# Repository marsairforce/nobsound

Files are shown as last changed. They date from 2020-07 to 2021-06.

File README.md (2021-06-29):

# Nobsound Tube Audio Amplifier Upgrade

I have [This](https://www.amazon.ca/Nobsound-Amplifier-Single-Ended-Handcrafted-Headphone/dp/B073ZXZ3Z5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) audio amplifier.

Specifications:

* Output power: 6.8W * 2
* Frequency response: 20Hz-20KHz
* Input impedance: 100K ohms
* Output impedance: 4/8Ω
* SNR: 90db
* Input Sensitivity: 500mv-2000mv
* Harmonic distortion: 1% (1KHz)
* Tubes
  * 1x 5Z4P
  * 2x 6H8C
  * 4x 6P1
* Operating voltage: 110V
* Weight: about 7 kg
* Size: 260mm x 215mm(including terminals and knobs 260mm) x 150mm (W*D*H)

Chassis is close to the Hammond [1441-22BK3](https://www.hammfg.com/files/parts/pdf/1441-22BK3.pdf)

It worked well for about a year.  But now there are some issues.

## Issues

* The rectifier tube is very noisy with 120Hz. Dynamic microphones anywhere within 1M of this amp pick up the hum when the amp is on. I did not notice or care about the EM radiation before I started using microphones on my desk. For a long time I had terrible hum coming through all my recorded audio. I just thought it was the shitty microphone, or the Art Tube MPC was not very good. But all along, it was the rectifier on my power amp.

* The amplifier gets quite hot. Even the audio transformers are almost too hot to the touch. I expect the tubes to be hot and the power transformer. But there is enough heat that it conducts onto the audio output transformer case. This is too hot I feel to put the amplifier in the shelf on my desk. I currently have it on top of the shelf. That allows heat to rise away from it better. But I would prefer to have it in my shelf and not worry about it lighting up my room. I think the heat is due to the five tubes here. If we had less tubes, there would be less heat. Particularly that rectifier tube.

* Why does a hi-fi audio amplifer even use a rectifier tube. Rectifiers have a lot of internal resistance. This creates a "spongy" effect when there is more demand for power, the output voltage is reduced. This cause compression or or reduced headroom on the output sound. Which is completely not what we want here. This is something perhaps useful in a guitar amplifier right. I think the only reason they used a rectifier tube instead of diodes here is because it looks cool. Or perhaps so they could say "all tube" (so a marketing reason).

* The preamp tube is recently gone bad. I hear terrible crackling on the left speaker. I tested this by swapping the preamp tubes and then had crackling on the right side.

* The balance of the audio is not equal on both sides. I hear a very noticable reduced volume from the left speaker. At first I thought it was the position of the speakers in the room or how I sit relative to the speakers. But I was able to swap the 6P1 tubes and then have a reduced volume output on the right side.

* Retubing this amp is about $200. And that is even when I can find these tubes. The 6H8C preamp tube is about $30 USD. But I can't even find the 6P21 tubes or the 5ZP4 rectifier tube domesically. They are all over Aliexpress. But I am not interesed in ordering (relatively expensive tubes for what they are) and having a long wait time to have them arrive here. I also have less confidence in these Chinese surplus tubes. That they are probably worn in before they were purposed for this amplifer. I don't think I have used my amplifier hard enough to need to replace a bunch of tubes after only one year. They must have been pretty worn out when I got them.

I don’t see the point in having special tubes, when I have a box of 12AX7 tubes and EL84 tubes from guitar amps. Why can't I just make this amplifier use these tubes?
More research,

* The 6H8C tube is basically like a 12AU7.
* The 6P1 is based off the EL90, which is a deficient earlier version of the EL84 tube.
* The 5X4P is just two assemblies of two 1N4005 diodes in series.

## First Wave of Modification

I started this around 2020-07-19 Where I was investigating tube characterstics. I realized, I didn't want to just rewire the tube sockets and hope for the best, but to create a schematic of the amplifier so I can undertand what it going on.

Observable results:

* Fixing the crackling sound from the worn out preamp tube. It is super silent now.
* Fixing the uneven volume levels. Both left and right now appear to have similar volume levels.
* Remove some inefficiencies and heat by replacing rectifier tube with diodes. It does feel like it runs a lot cooler anyway.

It does not look as cool without the bunches of interestingly shaped tubes, but I am hopeful it performs better. I depopulated the other tube sockets (for the 6H8C preamps and rectifier tube) So the old tubes can sit there and look pretty, but are not actually even being lit up.

## Second Wave of Modification

2020-07-24:  I went ahead and ordered all around new electrolytic capacitors from Digikey. I wanted some connectors for playing with Amateur radio stuff, and needed to pad an order to > $100. Waiting over the weekend for the parts to arrive.

2020-07-27: The parts arrived. Installed the new capacitors and re-assembled the amplifier.

## V3 Design

After all that work to put in the sensible auto standby startup circuit, the tubes were still sparking. Even after they were warm. I changed out the tubes. Still having crackling. Even on shutdown.

So there is something horribly wrong here.

It bothers me we have 3 terrible ad-hoc 5V power supplies too. Why do we have that nasty ground loop current draw problem anyway?

Take apart the amp. Gut it completely. Remove the turret board and the tube sockets.

AHA!!! The fucking transformer has center tapped filament supplies! And the center tap is going to ground.  Well that makes sense now why I could not attach a full bridge rectifier with ground reference here. Dammit. How come I didn't see those center tap wires before then?  They are black and cut short and twisted under everything to a ground lug under the standoff to the turret board. I guess I never took this all the way apart before. My schematic did not have the filament center taps on them too. So I was working with incomplete information before.

Doh.

Ok. So this time, going to change the tube sockets. These terrible Chinesium porcelean sockets are likely terrible for the tubes, cracking the pins or not even giving them a good connection. Of course I only have 2 more in stock. I need 4 here. Have to go order them.

Maybe at this point I will design a proper power supply board, for the capacitors and diodes I have. Since I last played with this I have som enice 1KV 1A SMA diodes. and also some nice 400V 8A DPAK diodes. These can be the bridge rectifier for the electronics.

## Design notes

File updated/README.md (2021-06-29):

# Nobsound EL84 Amplifier

This is the updated schematic of the (formerly 6P1) amplifier.

These are likely to change as I continue to hack it up and "improve" it.

## First Wave Enhancemnts

The objective here:

* To replace the 6H8C preamp tube per channel with a 12AX7 tube per channel.
* To replace the pair of 6P1 tubes per channel with a single EL84 tube per channel.
* The rectifier with regular diodes.

### EL84 Power Tubes

So based on the calculations (in the circuit analysis), to use an EL84, I would want the current through the cathode resistor to be about 40mA.  The resistor is 270 ohms, so I am looking for a voltage drop of about V=I*R or 0.04*270 or about 10V.

In practise plugging in an EL84 and testing it out I see it stabilized around 11.75V. Or about 43mA. This is perfect and exactly where we would like it to be.

Reading on https://www.18watt.com/viewtopic.php?t=12875 , the values we have is the values we should use. Ok then.

Wire in the amp and do a test. Well. it seems to work. Let’s do the right channel.
It sounds ok.

I keep reading and finding schematics where the screen resistor should go to the B+, not the output transformer the plate goes to. This amp seems to be wired incorrectly then?

Experiment to wire these to the B+. I only have the 100 ohm screen bypass resistors. I think it should be 1K.
But when I do this, a terrible hum sound and buzzing. Ok, put that back. It might be the hum was because the resistor was 10x too low from what is recommended in this configuration? This is something I would like to understand later.

### Conclusions

By 2020-07-29 I was able meet my original objectives. And to do so without purchasing any electronic components or tubes. Which for me and my projects is highly unusual. And now I have a special sense of smug-ness as well.

I orginally went with a 12AT7 tubes. As they have less gain then the 12AX7 tubes. But I found the sound to be crackly and brittle. I tried to replace the coupling capacitor (which is likely a 0.022uF capacitor) with a 0.1uF capacitor. This gives it a bit more bass response. But still not very good. I guess there is that problem were the 12AT7 is generally considered to be not musical at all. I ended up putting some old Mullard 12AX7 tubes I had in my junk drawer. They have "Holland" printed on them. And even do a really nice vintage filament flash when turning on. But they are really crisp and awesome sounding. Using old tubes (likely liberated from my Traynor amp) onto here is like a fine bottle of wine with peanut butter toast. But you only live once, so might as well enjoy the stuff I have rather than hoarding it forever and not using it.

### Amplifier channel schematic

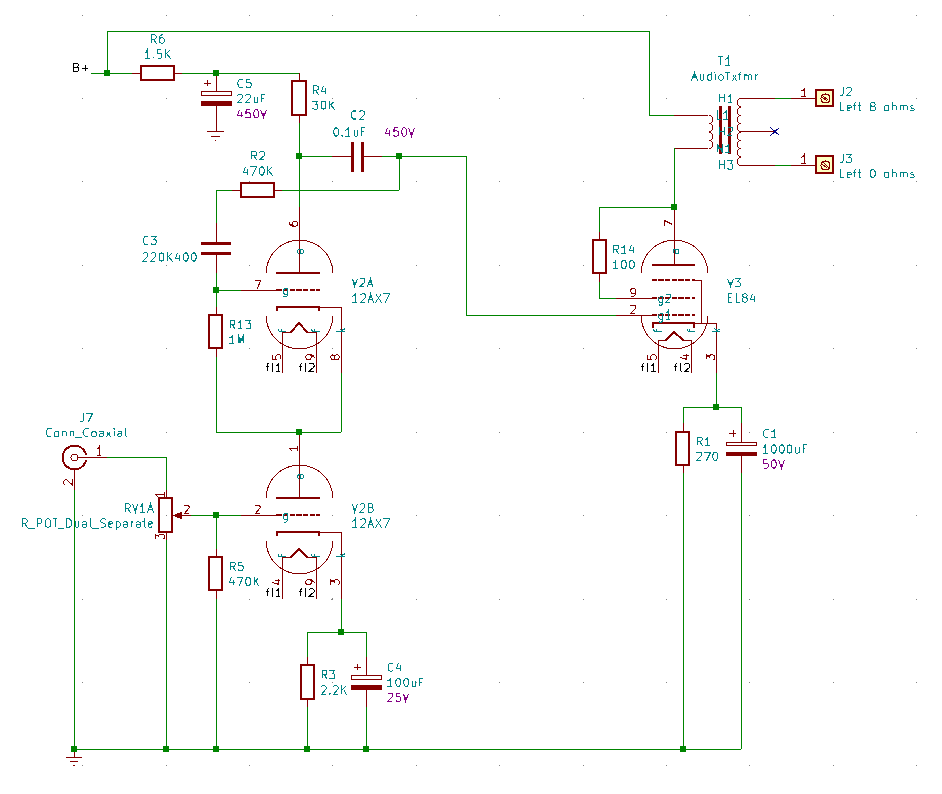
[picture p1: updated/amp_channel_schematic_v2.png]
V2 amp schematic


>R2 and C3 are incorrect here, these go to ground, and are not a feedback as indicated. I later discovered this while updating the schematic on 2020-08-31 for v2.3 revision.

### Power supply schematic

### Updated component list

We added the following parts (to the original schematic)

| Part | Value | Description |
|:--|:--|:--|
| V1 |  | (Removed) |
| V2 | 12AX7 | Left channel preamp tube |
| V3 | EL84 | Left channel power tube |
| V4 | | (Removed) |
| V5 | 12AX7 | Right channel preamp tube |
| V6 | EL84 | Right channel power tube |
| V7 |  | (Removed) |
| C2 | 0.1uF; 450V | (Updated from original schematic) |
| C10 | 0.1uF; 450V | (Updated from original schematic) |
| D5 | 1N4005 | Rectifier board |
| D6 | 1N4005 | Rectifier board |
| D7 | 1N4005 | Rectifier board |
| D8 | 1N4005 | Rectifier board |
| C17 | 47nF; 450V | Rectifier board |
| C18 | 47nF; 450V | Rectifier board |
| C19 | 47NF; 450V | Rectifier board |
| C20 | 47nF; 450V | Rectifier board |
| R21 | 220K; 2 watts | (bleeder resistor I added after C7) |

## Second Wave Enhancements

Some small updates.

* Replaced the electrolytic capacitors with United Chemicon branded capacitors. I have anxiety these capacitors are going to be the cheapest, poorest quality, Chinese made capacitors. Same voltage rating and values (except noted below).

| Part | Value | Old Brand | Notes |
|:-----|:---|:---|:---|
| C1 | 220uF | Samyoung  | This is now a 1000uF |
| C4 | 100uF | Samyoung  | |
| C5 | 22uF  | Samyoung  | |
| C6 | 150uF | Philips | |
| C7 | 150uF | Philips | |
| C8 | 22uF  | Samyoung  | |
| C9 | 100uF | Samyoung  | |
| C12  | 220uF | Samyoung  | This is now a 1000uF |

If they are even the brands they say they are. They could very well be counterfit even.

All I see in the forums is "Replace all Philips caps!!!".

Samyoung is a Korean brand, also known for their terrible quality and reliability.

* Changed the values of the EL84 cathode bypass capacitor from 220uF to 1000uF This is beacuse I have been reading larger capacitor values here help with improving lower frequency responses.
  * https://el34world.com/Forum/index.php?topic=9452.0

I would like to find a more technical calculation for this. So far the sounds do not sound bad. But I can not tell if or how much added bass response I actually have here. I still need to get around to doing a frequency response analysis of this amp.

* Replaced the charred looking 270 ohm resistors with new 270 ohm resistors. Though I ordered 3W kind, I think the old ones may have been 5W. Doh. Well. From the measured voltage and and computed current across this resistor, the power is only about 0.5watts. Though that was idle. I guess we should try to measure the voltage under full load somehow.  For now I will use them and if they burn up, I will replace them with higher power resistors.

## Third Wave Enhancements

The volume knob was all scratchy. I guess the cheap Chinese crap knob that was used just wore out. Funny because I barely even use this knob. And lately I still experience slight imbalance in volume from left to right side. This likely has to do with my room geometry. I would like to have separate volumes for left and right channels.

So had the idea to remove the VU meters (Since those are basically cheap Chinese crap as well and they do not really work for me. They barely deflect on all volumes and I basically never look at them on the amp. So in place of the VU meters to put a potentiometer for the volume control.
I cut a piece of 24ga aluminum I had handy and screwed it inside the chassis using the hardware for the VU meters. Then mounted two 1M pots. The same kind I used in my Traynor amp. They feel very satisfying to touch and turn. Using plastic knobs like I always have used on my amp and before on guitar. They are not ideal but do match the color scheme of black and silver.

I noticed after there was slight buzz on the left channel. Replace the preamp tube. That makde a big difference. I guess the old Holland tube I was using is finally done. Wish I had a kind of tester for tubes. It seems a lot of the way I approach tubes is magic, finding a specific tube works in a specific slot on a chassis.

## 2020-08-31 (v2.3)

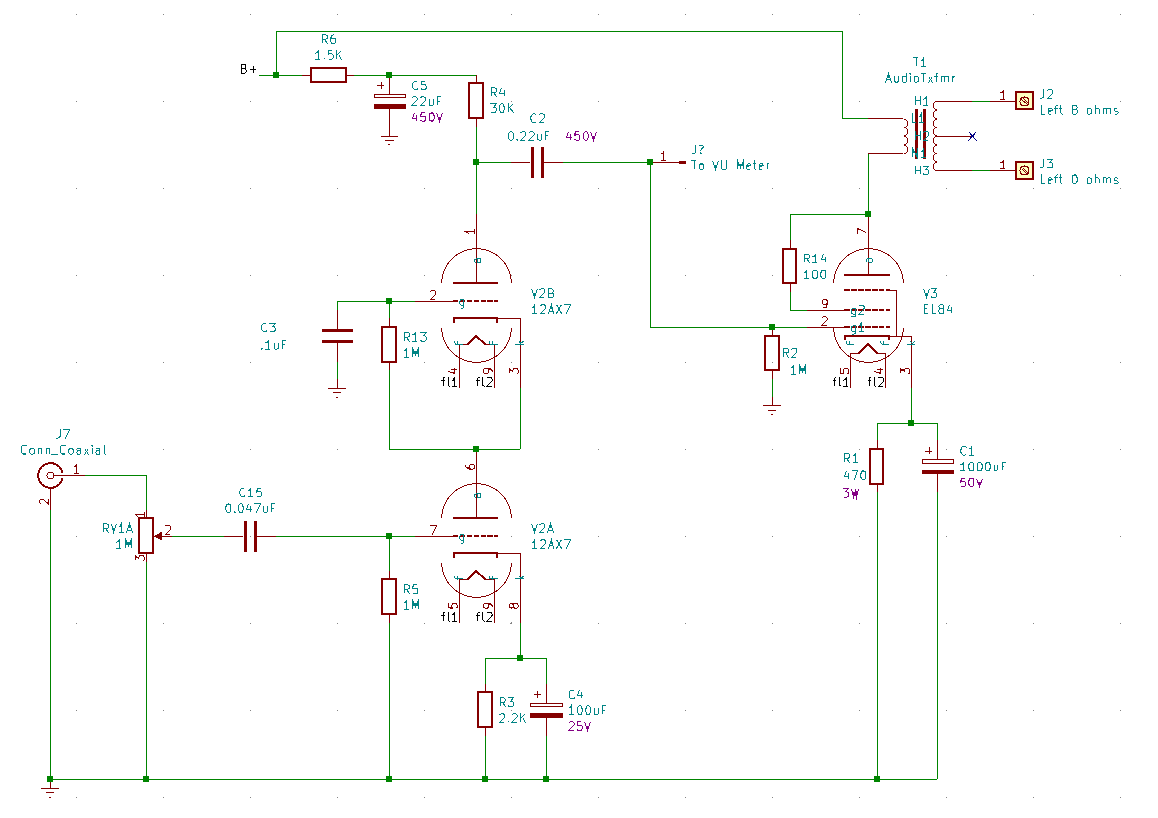
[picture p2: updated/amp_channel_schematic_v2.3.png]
Amp schematic v2.3


* Replace the EL84 cathode bypass resistor (R1, R11) from 270 to 470 ohms. I think it was running a bit too hot before.
* Notice there is no input capacitor to decouple the DC coming in. This is fucking why I get terrible hum when connecting to my Rolls MiniMix and computer audio. Install 0.047uF capacitor in series with inputs.
* Notice there is not Grid stopper resistor into the first stage of the 12AX7 tubes (V2, V5). Install a 4.7K grid stop resistor following the newly added input decoupling capacitor.
* Replace the 12AX7 input grid leak resistor (R5, R10) from 470K to 1M resistor. I think larger value will work better with the newly added decoupling capacitor and grid stopper resistor.
* Notice I had the A/B elements for V2, V5 switched in the schematic from how it is. Update the schematic.
* I had made an error in schematic before, The (C3, C11) actually go to ground, not feedback from 12AX7 output. And (R2, R12) is actually a grid leak resistor for th EL84. Ok. good. I was just about to add one of those.
* There is no grid stopper resistor between preamp output after the capacitor and the EL84. Add a 5.6K resistor.
* Change the EL34 grid leak resistors (R2, R12) from 470K to 1M
* Nicely mount the diode rectifier circuit board onto the inside side of the chassis with standoffs and screws. Before I had this just dangling loose and covered with a piece of tape.

This all came about as I was trying to attach one of those VFD spectum analyzers. It needs 5VDC. I have a 7805 type regulator. Make a rectifier and filter cap and circuit board to connect to the unused 5VAC fillament supply. I see 5V when I test it. And measure 4.9V on the VFD.  Maybe for some reason the VFD requires more current than the regulator IC can supply. I will investigate later.

For now I am excited that these small tunings will make the amp sound a bit less "shrill". It felt there was a bit too much presence or high end sometimes, especially with sounds of people talking.

Since there was no input capacitor, I bet that is why we were having shitty noise when connecting this to the mixer. And why I went on that foxhole to get the Art clean pro. Try to connect the amp directly to the mixer now. Heh. no noise. When crank it up there is the usual high pitch buzz. But that is always there on high gain settings. The hum sound is gone. So I can put away the clean pro box. One less part, and three less cables, on the desk.

## 2020-09-01

Come back to revisit the VFD spectrometer upgrade.

Connect the power supply module I made to a lab power supply. At first I had fun experience of having to whack the power supply to make it work. Cheap Chinese crap strikes again. But it seems the 7805 (or switching regulator version of the one I have) needs at least 9V input to make it turn on. With the loading effect of the VFD anyway.  So with the 5VAC filament this was enough to give me a 5V regulated output on open circuit. But under load this was not enough input voltage.
The total current draw seems to be  about 260mA at 10V input. or 2.6W.

I have one of these small DC-DC converters that takes in 4-9V and then puts out 5V. so let's try this. Hm. The module I have is only 2 watts. That is going to push this pretty hard. Maybe let it run on my desk a bit to see if it burns up after a bit.

It seems to work when I power it off the 5V supply as a clock. But once it starts to work as a display for audio it cuts out and reboots. This means likely that the 5V supply from the transformer can not source enough current here. Try to switch my power supply module to use one of the filament supplies. Ok. that seems to work, and not hose the amp. I bet this is somehow a weak ass counterfit transformer. Maybe I am used to Traynor transformers.

Have the idea to replace the 12AX7 sockets with shielded sockets. I didn't really have a problem with noise. But mounting the VFD spectrograph meter on the chassis in front of the tubes, it is likely I would now be picking up stray  noise from this thing. You can hear the switch supply on it even. The shielded sockets I have are not very good. But they were a lot better than the likely counterfit sockets that were on the chassis. They just fall apart as you take them off.

The VCD appears to work. I mounted it to the chassis with some furniture brackets I had and sheet metal screws. Drill hole to put wires into the chassis. The power supply is inside on the side of the chassis on stand offs. When there is no sound playing there are no bars stuck on a little bit (like I had when I connected this to the output of my computer audio interface, or mixer headphones before). So this allows the clock to turn on. For a while I have been just using this as a clock.

## 2020-09-06

I felt lately the nobsound sounded like i "had a blanket over the speakers". Craking up the master level on the Rolls mixer seems to do less effect than it used to.

Adding that 5.6 k resistor between the preamp and poweramp stages I think. And I don't really need the 4.7K on the input either.

* Go delete R15, R17, R19, R20.

## 2020-10-07 (v2.4)

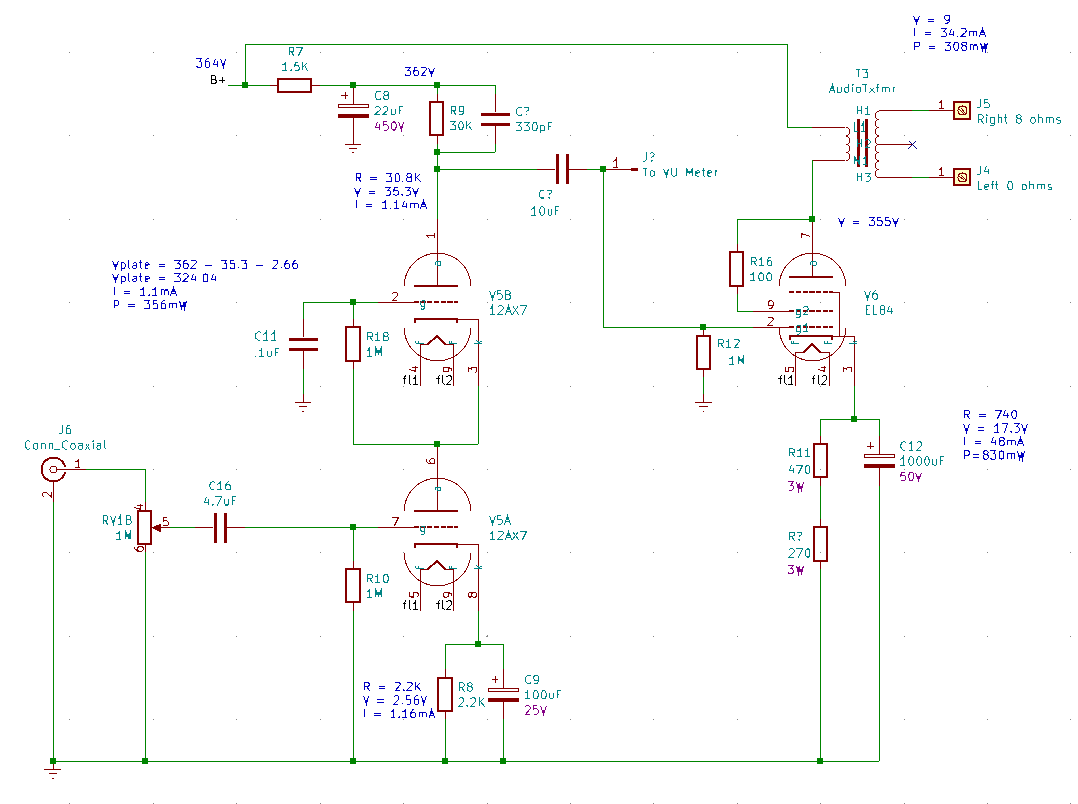
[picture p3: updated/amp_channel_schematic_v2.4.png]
Amp schematic v2.4


Replace the 0.22uF capacitor with some not-counterfeit capacitors.  I only had 0.1uF, so putting two of these in parallel.

I think the EL84s are still running a bit too hot.

Also the right and left channels have slightly different volumes for the same knob position.

Measure voltages and resistances. Compute currents.

Experiment with different cathode load resistors for the EL84. I find a 1.2K resistor gives us a good 84% plate dissipation (according to https://robrobinette.com/Tube_Bias_Calculator.htm )

Experiment with a constant current source using transistors. I can only get up to about 40mA on this. I think the voltage drop through the transistors with the high impedance here is losing some of the current?

Experiment with different resistors.

Max cathode current is [65mA](https://en.wikipedia.org/wiki/EL84).

I am getting about 68 to 70mA right now with just the 470 ohm resistor in there.

Find that when I put in the 270 ohm resistor I used to have in there, in series with the 470 ohm (so 740 ohms total) I am able to get about 50mA cathode current.

I like the idea of tinkering with current sources, but to add all this stuff and an adjustment knob when just 2 resistors will work well enough seems silly.

I would use a single resistor. But these are what I have in stock at the moment.

So updating both channels with this series resistor. I now am using about 40-60mA less from the power supply. I think it is no longer doing that high pitch whine from the transformer like it would before. Just the noise from the inverter in the VFD module now.

Put the amp back together for now.

Nope.

It felt a little too much high end now. It is good that it feels more sparkly. Likely less loading the power suppy it is able to do higher frequencies. But it is too bright for my tastes.

* Replace the input bypass capacitors from 0.047uF to 4.7uF. I used SMD ceramics soldered to pin headers, soldered to the wire. Awesome hack.
* Replaced the 2x 0.1uF coupling capacitor between preamp and power amp with a 10uF 250V. its probably fine.
* Added a 330pF 400V bypass cap onto the plate of the preamp. Hoping this helps tame the higher frequencies a bit.

Ok. back together now it sounds better bass response and less of that too much fizzy it was.

## 2021-04-25 (v2.5)

I replaced the EL84 tubes with some new Tungsol tubes. But now I was getting arcing when the tubes were cold.

* Add a soft standby switch - A RC time delay, Schmitt trigger to drive a MOSFET to engage the high voltage to the tubes after they had time to warm up.
* A buffer circuit to drive the VFD to remove some annoying audio bleedover.

I was still getting tube arcing though. These were new tubes. Try some other tubes. Nope still getting arcing.

Measure the voltage across teh tubes. It is way too high. around 390.

Also measure the voltage across the filaments. It is about 6.9V. This is also too high, more than 10% out of spec.

Rip apart the entire amplifier out of anger. The main power transformer is just "too hot".

Discover the filament lines were center tapped. Oh. So that is why I have not been able to add rectifiers to this. Makes sense now. I was fighting the ground reference there in the transformer.  Fucking hell.

Also pissed off at these shit ceramic tube sockets. I think these things are cracking my tubes and causing them to be dead after resocketing them a couple times, as I do for testing. I lost 2 new preamp tubes recently for no reason.

## 2021-05-15

* Order new Belton tube sockets. Install them onto chassis.
* Disconnect the ground reference on the filament windings.
* Use one filament winding to power the bridge rectifier and 5V regulators I have in there for the 5V things, like the display, the soft start circuit, the buffer for the display.
* Experiment with using a full bridge rectifier and [these](https://www.monolithicpower.com/en/mp2307.html) regulators I got from Aliexpress. They say rated up to 3A. I have about 2.34A measured here. Let's try these out.
Build a full bridge rectifier using [SDURD840](https://www.digikey.ca/en/products/detail/smc-diode-solutions/SDURD840TR/6022668) diodes. It is what I had handy.
* In actuality, I am only able to deliver about 4v at 0.5A to the tubes from this regulator module. The load of only 1 tube flattens out its output voltage. This is not anywhere near its rated 3A capacity. I guess this is exactly what I should expect from something I get off Aliexpress, where it is made entirely from counterfeit parts from China.
* Try another [random](https://datasheetgo.com/xl6009e1-datasheet-regulator/) Aliexpress buck converter module I have. This one sais "up to 4A" - Also fail. It can't even drive one tube. There is either some silly short circuit protection here, that these topologies of converters can't power tube filaments. Or these are just crap modules.

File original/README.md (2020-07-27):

# Nobsound 6P1 Original Schematic

This is the original schematic and my notes as I was investigating, learning, and discovering.

## Original Schematic

To start the schematic we need to label components.

With the amplifier oriented upright and when you are facing the front of the amplifier, going from left to right, and then front to back.

### Amplifier Channel Schematic

This is the left channel.  The right channel is a mirror image of this for physical component layout, and has the same values and circuit.

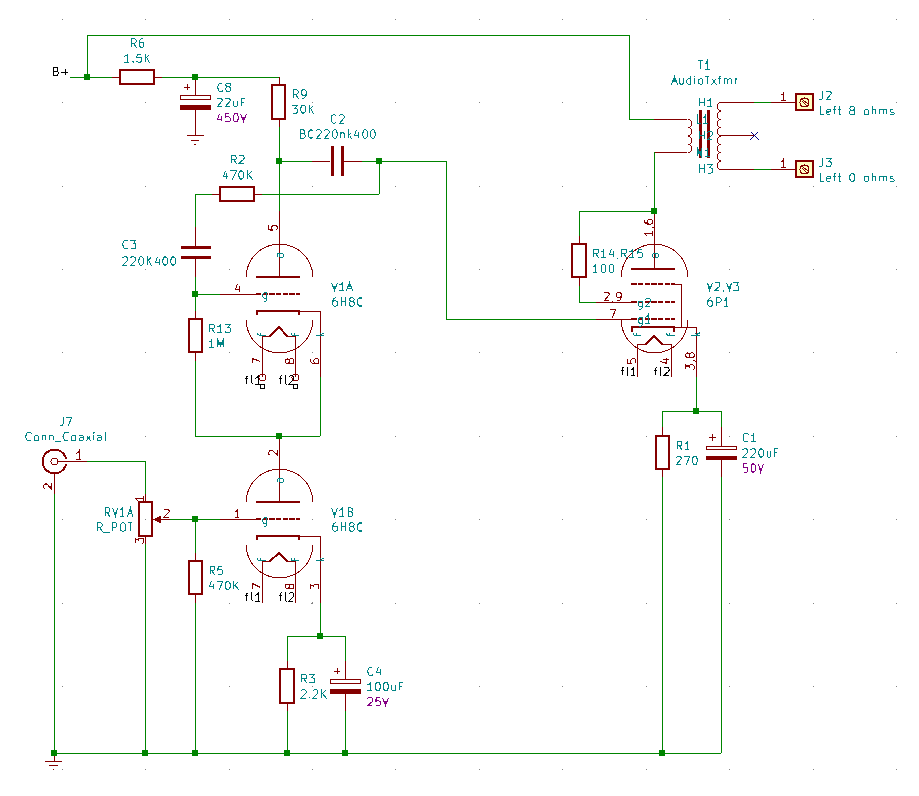
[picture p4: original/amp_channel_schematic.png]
Amplifier Channel


### Power Supply

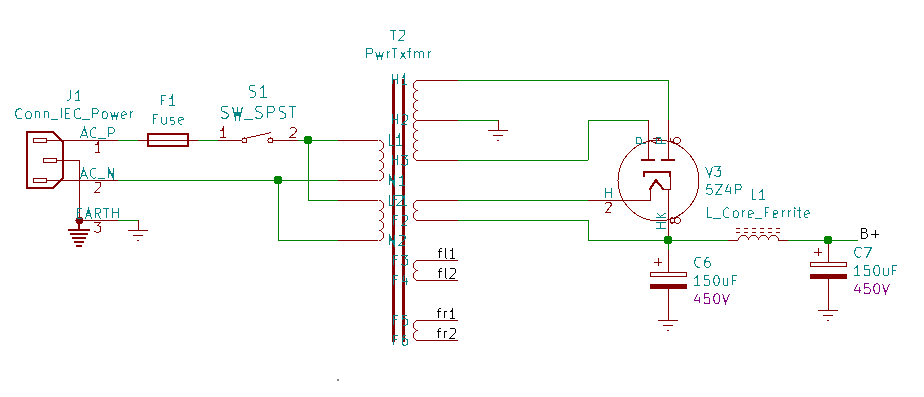
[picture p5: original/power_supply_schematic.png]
Power Supply


### Component List

| Part | Value | Desc |
|:-----|:---|:-----|
| V1 | 6H8C  | Left channel preamp tube |
| V2 | 6P1 | Left channel power tube - front (1 of 2) |
| V3 | 6P1 | Left channel power tube - rear (2 of 2) |
| V4 | 5Z4P  | Rectifier tube |
| V5 | 6P1 | Right channel power tube - front (1/2) |
| V6 | 6P1 | Right channel power tube - read (2/2) |
| V7 | 6H8C  | Right channel preamp tube |
| S1 | EG4810-ND | Power switch (Front) |
| RV1  | Dual potentiometer | Volume knob |
| J1 | Q203-ND | Nema power connector with fuze |
| F1 | | Fuze (in the power connector) |
| J2 | 314-1205-ND | Left channel 8 ohm output |
| J3 | 314-1206-ND | Left channel 0 ohm (gnd) |
| J4 | 314-1206-ND | Right channel 0 ohm (gnd) |
| J5 | 314-1205-ND | Right channel 8 ohm output |
| J6 SC2440-ND | Right channel input |
| J7 | SC2440-ND | Left channel input |
| T1 | HM4585-ND | Left channel output transformer PRI:291 ohms |
| T2 | HM5045-ND | Power transformer |
| T3 | HM4585-ND | Right channel output transformer |
| L1 |  | Power supply choke (inside chassis) |
| C1 | 220uF; 50V | Power tube cathode bypass capacitor |
| C2 | BC220nK400 | Coupling between preamp and power amp. 0.220uF ; 400V?  I replaced these with 0.1uF |
| C3 | 220K400 | |
| C4 | 100uF; 25V | |
| C5 | 22uF; 250V | |
| C6 | 150uF; 450V | |
| C7 | 150uF; 450V | |
| C8 | 22uF; 450V | |
| C9 | 100uF; 25V | |
| C10 | BC220nK400 | (replaced with 0.1uF; 450V) |
| C11 | 220K400 | |
| C12 | 220uF; 50V | |
| R1 | 270 ohm; 3 watts | Cathode bypass resistor, left channel |
| R2 | 470K; 2 watts | |
| R3 | 2.2K; 2 watts | |
| R4 | 30K; 2 watts | |
| R5 | 470K; 2 watts | |
| R6 | 1.5K; 2 watts | |
| R7 | 1.5K; 2 watts | |
| R8 | 2.2K; 2 watts | |
| R9 | 40K; 2 watts | |
| R10 | 470K; 2 watts | |
| R11 | 270 ohms; 3 watts | Cathode bypass resistor, right channel |
| R12 | 470K; 2 watts | |
| R13 | 1M; 1 watt | (On socket of V1) |
| R14 | 100 ohms; 1 watt | (On socket of V2) |
| R15 | 100 ohms; 1 watt | (On socket of V3) |
| R16 | 100 ohms; 1 watt | (On socket of V5) |
| R17 | 100 ohms; 1 watt | (On socket of V6) |
| R18 | 1M; 1 watt | (On socker of V7) |
| M1 | | (VU meter for left channel, on front) |
| M2 | | (VU meter for right channel, on front) |
| R19 | 15K; 1/2 watt | (Behind M1) |
| R20 | 15K; 1/2 watt | (Behind M2) |
| C13 | 2uF; 50V | (Behind M1) |
| C14 | 2uF; 50V | (Behind M2) |
| C15 | 10uF; 50V | (Behind M1) |
| C16 | 10uF; 50V | (Behind M2) |
| D1 | 1N914 | (On J3) |
| D2 | 1N914 | (On wire to M1, after D1) |
| D3 | 1N914 | (On J4) |
| D4 | 19N14 | (On wire to M2, after D2) |
| LED1 | blue | On front |
| R21 |  | Inline on wires to LED1 |
| RV1 |  | (On front) Dual potentiometer volume knob |

### Original Schematic Observations

* The way the components to the VU meters are soldered inline with the wires to the connectors and the meters make me think this is a sort of add-on accessory or module. And they just hack it in with the least amount of effort and quality. It is likely they made these as a sort of sub assembly and just scabbed it in as needed. I should fix these inline components with a small circuit board module with nice plug-in connectors too.
* These capacitors are probably the cheapest quality parts ever, made of chineesium. I should likely consider replacing them, or even changing the values if I need to support different currents.
* Two of these resistors look a little burnt. They are likely the cathode bias resistors on the power tubes. I think these are metal film resistors by the pattern of spiral on the body. The resistors still work. So it is likely just the paint and color stripes has burned off. But That is still not good. Regular operating of this amplifer should not make these parts get this hot. Unless the tubes are really burning out so that there is a lot more current flowing through them than normal. It might be that the tubes were not red plating because the power transformer (or the rectifier tube) can not source enough current to do so. It might explain why everything was so hot too.  I should replace those with higher wattage values.
* The resistors look like they are all about 2 watt. The ones on the preamp don’t need to be this high wattage. Also These look like carbon resistors. Probably the cheapest quality as well. I should replace them with metal film resistors.
* Filament wires are everywhere. Not very well twisted. The VU meters have filament supply for probably the lamp inside them. And these are not even attempted to be twisted. I think Ill just rewire all these. Oddly there seems to be 2 filament wire outputs. One for each channel. Maybe this is a thing for stereo amplifiers. I need to clean up the filaments when I pull and repurpose the sockets too.
* The point to point wiring is atrocious. There are components dangling everyhere. A leg of the capacitor goes down unshielded to the preamp tube sockets. Unworkable and dangerous. I think I will work on replacing the point to point wiring with small circuit board parts as well. But then pretty soon I am going to be designing a circuit board and having that made and then using surface mount parts.  There really are 2 boards.. A power supply board, and a channel board.  The VU meter parts can go on the channel board. This is going to cost a lot of money and time. For now fixing the amplifier is kind of a weekend project.
* This amplifier has no bleeder resistors across the filter capacitors. This means there could be a dangerous voltage across the capacitors for some amount of time after the amp is shut off, if the output tubes were not working, as they serve to load the power supply through the output transformers as this is a single ended class A amplifier. I am going to add a bleeder resistor. (I had a 220k, 2W resistor in stock)

### Other Observations

* The power transformer seems to have 4 wires, 2 primaries. They appear to be connected in parallel. I guess this is how they handle the 120/240V thing?
* The preamp triodes are stacked, in what is called a “cascode” http://www.valvewizard.co.uk/cascode.html
* Looking at the original schematic, I question the placement of the second grid resistor. It is connected to g2 on the tube side of the audio transformer, not the HT side, as in http://www.valvewizard.co.uk/se.html  I feel this could be laziness or poor design. But I tried moving the screen resistor to B+ and I heard terrible buzzing and hum sounds. This might be because I had shifted the bias too far to make the tube turn on more and was drawing too much current. It is likely the power supply filtering is just rubbish as it is, and the having the screen resistor after the audio transformer of B+ helps to filter that out, due to the inductive properties of the transformer?  Maybe if I added a filter capacitor there it would help?  For now I will leave the screen resistor as it is, but I want to understand why it is this way at some point.
* Also, there is not feedback to the preamp from the output, as in https://www.bonavolta.ch/hobby/en/audio/el84_1.htm . We could add a feedback and get a tone control as well, as in https://www.bonavolta.ch/hobby/en/audio/el84_3.htm

### Measurements

Voltage from output of transformer onto the rectifier tube: 580V. This is the outer ends of the secondary. Because the center tap ground. The voltage across the rectifier will be about half.
Measuring the center tap, I see 287.5 and 285V.

I measured the voltage at the B+ after the filter capacitor, where it goes into the output transformer and the preamp. It is 390V.  And as I predicted, without bleeder resistors in there the voltage was very high for several minutes after.
With one 6P1 tube, B+ was 343V and the voltage does fall off very fast, if the tube was
With all original tubes in, the voltage goes up to 370, but goes down to 306V when they warm up.

Voltage across the 6P1 plate to ground: 282V

Measure the voltage across R1, the cathode bias resistor for the 6P1s: Starting at 18V,stabilized around 18.8V. R1 is  270 ohm. So that is I = V/R or 7mA

Plate to cathode voltage: 263V

So according to https://robrobinette.com/Tube_Bias_Calculator.htm

Measure the resistance on the primaries of the output transformers.  T1 (L):291 T3 (R):288
So assume plate to cathode voltage is the same, 263. The left channel would have .90A and the right channel would have .91A

## Enhancements Approach

Have the idea of replacing

* The 6P1 tubes on my audio amp (which are EL90 / 6BQ5 equivalent) with EL84 tubes.
* The preamp tubes (6H8C) with 12AX7 tubes
* The rectifier with regular diodes.
* The inputs to this is unbalanced audio (RCA Jacks) Since my audio interface is balanced (TRS) output. It would be neat if I had the option of putting balanced audio into this as well.

An approach might be to attempt to replace the power tubes on one channel with an EL84. That is rewire the 2 sockets that are in parallel to handle 6P1 tubes, to instead be a single socket to handle an EL84. This will free up one of the 9 pin sockets for experimenting with building a new preamp circuit.

Then we can try to build a new 12AT7 based preamp. We can likely also not even touch the existing preamp circuit, just depopulate the tubes and build a preamp on a perf board and connect it into the power stage, to evaluate the performance and quality of the sound.

Independent we can work to move the rectifier and filter caps to a power supply section. That gets the high voltage stuff out of the central turret board, which I feel makes tinkering over all a bit safer.

## Power Tubes

This is just a different socket and slight re-mapping of pins. It makes sense because I have a pile of el84 tubes from guitar amplifier fittings.  And to buy EL90 tubes (from tubedepot is like $20 per tube, when they are in stock. But lately they are not in stock).

So we could probably get away with a single EL84 per side instead of the two 6P1 tubes there are now, because the EL84 is rated for about twice as much power.

* https://www.radiomuseum.org/tubes/tube_6p1p.html
* https://www.jj-electronic.com/en/el84-6bq5

### 6P1 Pinout

| Pin | Function |
|:----|:---|
| 1 | a |
| 2 | g2 |
| 3 | k,g3 |
| 4 | f |
| 5 | f |
| 6 | a |
| 7 | g1 |
| 8 | k,g3 |
| 9 | g2 |

### EL84 Pinout

| Pin | Function |
|:----|:---|
| 1 | |
| 2 | g1 |
| 3 | k,g3 |
| 4 | f |
| 5 | f |
| 6 | i.c. |
| 7 | a |
| 8 | i.c. |
| 9 | g2 |

### Pin Mapping from 6P1 to EL84 Conversion

| 6P1 | EL84 | Function |
|:----|:-----|:---|
| 1 | 7 | a |
| 2 | 9 | g2 |
| 3 | 3 | k,g3 |
| 4 | 4 | f |
| 5 | 5 | f |
| 6 | 7 | a |
| 7 | 2 | g1 |
| 8 | 3 | k,g3 |
| 9 | 9 | g2 |

Since the amplifier already has 9 pin sockets, I can just use the sockets in the chassis.

Also since I only need 1 EL84 tube for what was 2 6P1 tubes before, I can consume and re purpose the 2nd 9 pin socket that was for the 2nd 6P1 tube per channel, to be used for the preamp tube (see below). Because I need to de-populate the 8 pin socket that was used for the 6H8C tube before.

## Preamp Tubes

The 6H8C is apparently equivalent to a 6SN7 . I can only find the 6H8C on aliexpress. Fuck that. Looking up, this is actually more like a 12AU7 tube

* https://www.jj-electronic.com/images/stories/product/preamplifying_tubes/6sn7/6SN7.pdf
* https://www.jj-electronic.com/en/ecc82-12au7

### 6H8C Pinout

| Pin | Function |
|:--|:--|
| 1 | g2 |
| 2 | a2 |
| 3 | k2 |
| 4 | g1 |
| 5 | a1 |
| 6 | k1 |
| 7 | f |
| 8 | f |

### 12AX7 Pinout

| Pin | Function |
|:--|:--|
| 1 | a1 |
| 2 | g1 |
| 3 | k1 |
| 4 | f |
| 5 | f |
| 6 | a2 |
| 7 | g2 |
| 8 | k2 |
| 9 | fc |

### Pin Mapping from 6H8C to 12AX7 Conversion

| 6H8C | 12AX7 | Function |
|:--|:--|:--|
| 1 | 7 | g2 |
| 2 | 6 | a2 |
| 3 | 8 | k2 |
| 4 | 2 | g1 |
| 5 | 1 | a1 |
| 6 | 3 | k1 |
| 7 | 9 | fc |
| 8 | 4,5 | f |

2020-07-21

I was able to depopulate the 2nd 6P1 power tube, to free up a 9 pin socket. Then I ported the wires over from the 6H8C socket.
This was facilitated by rewiring all the wires from the turret board and replacing all of the filament wires.

I did the left side only, as a test. Plug it in. And it worked right away. Ok. good.
But then I guess I randomly grabbed that bad tube for the right socket. Nuts. Well. Might as well change both sides now (I would have been happy to leave it for now to have it working even if there was a mismatched preamp on left/right. This would be better so I could compare how things sound and volumes. But I want to get rid of the scratches and popping sounds. So back to the workstation to change the right channel.

I will work on the power tube upgrade some other time. And will use it for a bit with just the preamps updated and one 6P1 power stage tube. It is 3 AM now, so I can’t test how loud it can go, but so far I notice I am able to create what sounds a bit like breakup in the audio if I drive the gain too high. This might because the power stage is in a diminished state. But it is most likely I need to review the component values around the preamp and learn how cascode amplifier stage works and then perhaps re-bias them.

I tested using a 12AX7 in the slot. I can not hear that noticeable difference. And I can get that slight bit of break up using a 12AT7.
I tried a 12AU7. It seems to work, but then I think I hear a lo-fi background static sound on high volume setting. And it is just a bit noticeably quieter. And I only have one of these. So I will use the 12AT7’s in there for now.

I came back and put in a 0.1uF capacitor as the coupling between preamp and power section. That seems to help with the lower frequencies.

Rectifier Tube

This is a 5Z4P
* https://www.radiomuseum.org/tubes/tube_5z4p.html

TODO: table

There is some discussion that when replacing a rectifier tube with diodes you need to use a series resistor to simulate the voltage drop caused by the tube.
I don’t like how there is not a bleeder resistor on the B+ filter capacitors. Add a 220K ohm resistor across the B+ capacitor. Before there was still 15V charge on the capacitors several minutes after the power was off. Now the bleeder pulls it down right away below 9V. Excellent. The current through this resistor is about 1.5mA. Entirely reasonable. Why did they not spare $0.06 to put this in?.

I have concern that changing to diodes would cause inrush current to the tubes before the heaters are hot, so this could cause arcing. That we should add protection circuits  TODO

Currently (after replacing the 6P1 output tubes with EL84, 6H8C tubes with 12AT7), the B+ voltage seems to be 330V.

I built a small diode rectifier board. Where I put two 1N4005 diodes in series so they are safe for up to 1200V. I am probably ok to use just one diode here, but wanted to be safe. I put 0.047uF (47nF) 630V capacitors in parallel with the diodes so the voltage is evenly divided across each diode, as discussed http://www.valvewizard.co.uk/bridge.html

The choice of diodes and capacitors was more because this was what I had in stock.
I put them onto a small punch board and soldered them point to point. Used spade connectors and insulated crimp connectors on the wires from the transformer and choke. This is now the similar construction as I have done in my Traynor guitar amplifier.

Upon turning on the amp. At first it was 380V. When the tubes warmed up it stabilized at 330V.  This is 20V more than what we had with the rectifier tube.
Measuring the EL84 cathode bypass resistor value, it continues to be 11.75V as it was before with the EL84s on the rectifier tube.

So far the amp appears to perform the same as it has with the rectifier tube. There is just a bit more voltage driving the plates. I will need to test it with loud volume tomorrow. But I expect it to appear louder without the spongy effect of the rectifier tube.

If anything it will run collectively a little bit cooler, I think a lot of its heat dissipation was the inefficiencies of the rectifier tube.

## Balanced Inputs

This is basically ripping off the circuit that is part of the ART clean box pro. Rather than needing to have that box and its cables and power cord, just embed the half of the circuit we use, into the amplifier. If I miniturize the components with a nice circuit board this should be reasonable to fit it in. It is going to be an op amp.
Related I should upgrade the op-amps in this. The cleanbox uses 4580D op amps. Those are pretty good. I just really love the OPA2134 op amps. I will leave the cleanbox alone but build my version with socketed DIP op amps
Here I only really need half the circuit. The cleanbox pro has two separate audio circuits.

The power supply was a wall wart. It takes 7.5 to 12 VAC. I can probably use the filament transformer winding from the removed rectifier tube or one of the audio sides to get this.

I should add 2 ¼” jacks with a switch so that when the jack is not inserted it will allow the unbalanced input.

I think this is totally a scope creep kind of thing. I just wanted to replace a tube, now I am rebuilding all the tubes and adding a balanced input option.

Or some inspiration of using tubes https://glass-ware.stores.yahoo.net/batoun.html

This is on hold, as it requires buying components. Really there is not much space left inside this amp chassis. I think leave it as it is and if I really feel the itch to build this, I should just build my own amp.

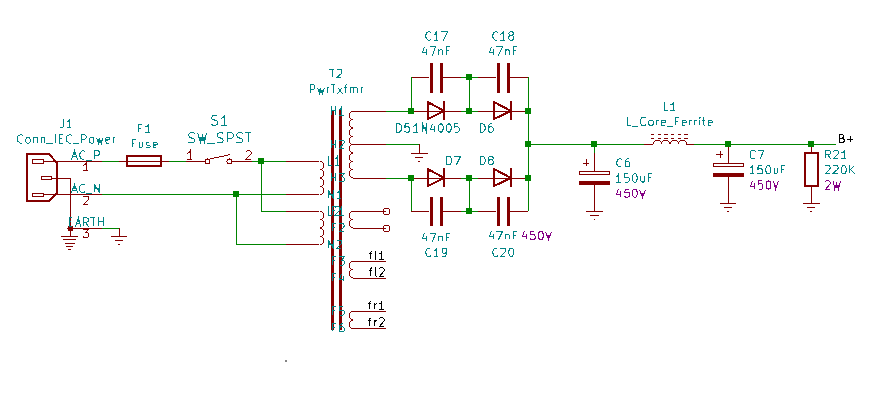
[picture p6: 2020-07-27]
updated/power_supply_schematic_v2.png

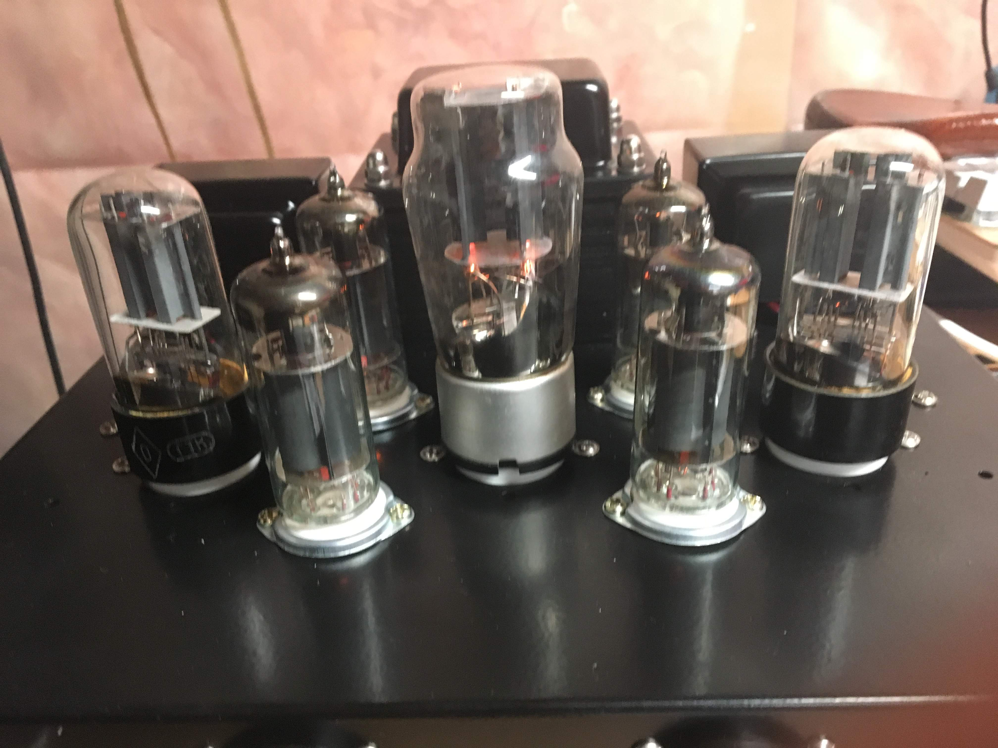
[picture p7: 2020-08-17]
pictures/58015715255__8B0F189D-5AB5-479C-83D0-3D9268BF2D.jpg

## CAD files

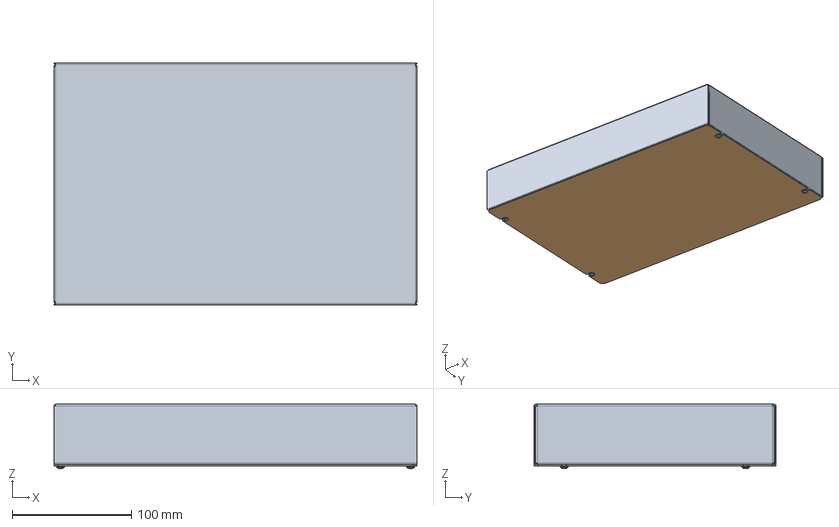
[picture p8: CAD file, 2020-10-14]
nobsound.FCStd
304.8 x 203.2 x 54.2 mm
6-32 (SC18394)
6-32 (SC18394)001
6-32 (SC18394)002
6-32 (SC18394)003

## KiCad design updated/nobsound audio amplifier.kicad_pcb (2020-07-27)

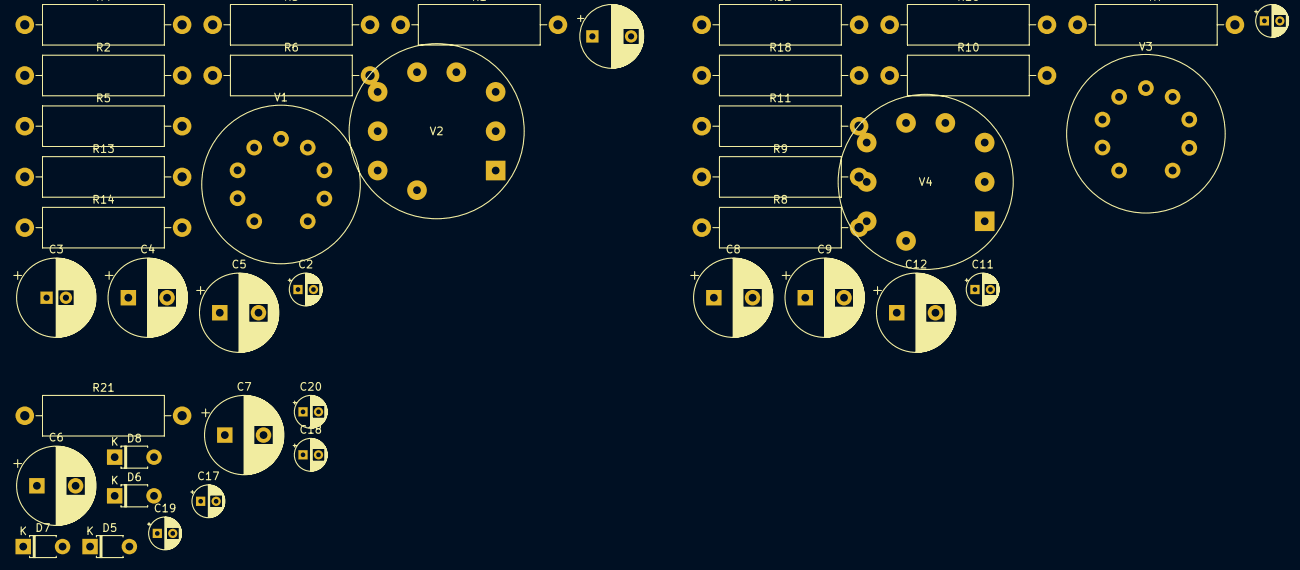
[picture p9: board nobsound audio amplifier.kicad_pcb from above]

Board: 2 copper layers, 41 parts (0 on the bottom side), 33 nets, no tracks yet.

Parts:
C1: 220uF; CP_Radial_D8.0mm_P5.00mm
C2, C10: 0.1uF; CP_Radial_D4.0mm_P2.00mm
C3: 220K400; CP_Radial_D10.0mm_P2.50mm
C4, C9: 100uF; CP_Radial_D10.0mm_P5.00mm
C5, C8: 22uF; CP_Radial_D10.0mm_P5.00mm
C6, C7: 150uF; CP_Radial_D10.0mm_P5.00mm
C11: 220K400; CP_Radial_D4.0mm_P2.00mm
C12: 220uF; CP_Radial_D10.0mm_P5.00mm
C17, C18, C19, C20: 47nF; CP_Radial_D4.0mm_P2.00mm
D5, D6, D7, D8: 1N4005; D_T-1_P5.08mm_Horizontal
R1, R11: 270; R_Axial_DIN0516_L15.5mm_D5.0mm_P20.32mm_Horizontal
R2, R5, R10, R12: 470K; R_Axial_DIN0516_L15.5mm_D5.0mm_P20.32mm_Horizontal
R3, R8: 2.2K; R_Axial_DIN0516_L15.5mm_D5.0mm_P20.32mm_Horizontal
R4, R9: 30K; R_Axial_DIN0516_L15.5mm_D5.0mm_P20.32mm_Horizontal
R6, R7: 1.5K; R_Axial_DIN0516_L15.5mm_D5.0mm_P20.32mm_Horizontal
R13, R18: 1M; R_Axial_DIN0516_L15.5mm_D5.0mm_P20.32mm_Horizontal
R14, R16: 100; R_Axial_DIN0516_L15.5mm_D5.0mm_P20.32mm_Horizontal
R21: 220K; R_Axial_DIN0516_L15.5mm_D5.0mm_P20.32mm_Horizontal
V1, V3: 12AX7; Valve_ECC-83-1
V2, V4: EL84; Valve_Noval_P

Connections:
/Sheet5F1E3F4C/B+: C7.1, R21.1
/Sheet5F1F04D1/fl1: V1.4, V1.5, V2.5
/Sheet5F1F04D1/fl2: V1.9, V2.4
/Sheet5F200EB8/fl1: V3.4, V3.5, V4.5
/Sheet5F200EB8/fl2: V3.9, V4.4
Earth: C1.2, C4.2, C5.2, C6.2, C7.2, C8.2, C9.2, C12.2, R1.2, R3.2, R5.2, R8.2, R10.2, R11.2, R21.2
unnamed: C1.1, R1.1, V2.3
unnamed: C2.1, R2.1, V2.2
unnamed: C2.2, R4.1, V1.6
unnamed: C3.1, R2.2
unnamed: C3.2, R13.1, V1.7
unnamed: C4.1, R3.1, V1.3
unnamed: C5.1, R4.2, R6.1
unnamed: C8.1, R7.1, R9.2
unnamed: C9.1, R8.1, V3.3
unnamed: C10.1, R12.1, V4.2
unnamed: C10.2, R9.1, V3.6
unnamed: C11.1, R12.2
unnamed: C11.2, R18.1, V3.7
unnamed: C12.1, R11.1, V4.3
unnamed: C17.1, C18.2, D5.1, D6.2
unnamed: C17.2, D5.2
unnamed: C6.1, C18.1, C20.1, D6.1, D8.1
unnamed: C19.1, D7.2
unnamed: C19.2, C20.2, D7.1, D8.2
unnamed: R5.1, V1.2
unnamed: R10.1, V3.2
unnamed: R13.2, V1.1, V1.8
unnamed: R14.1, V2.7
unnamed: R14.2, V2.9
unnamed: R16.1, V4.7
unnamed: R16.2, V4.9
unnamed: R18.2, V3.1, V3.8

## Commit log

2020-07-26 kick off project
    start readme files based on the contents of a google document I started before.
    Schematic file for the original amplifier as well as started an updated schematic. I prefer to keep these separate so I can compare as time goes on.
    [left_channel.sch, nobsound audio amplifier.kicad_pcb, nobsound audio amplifier.sch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]
2020-07-27 finish updated schematic
    Convert tables from google doc to markdown to have these in this repo
    [left_channel.sch, nobsound audio amplifier.kicad_pcb, power supply.sch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]
2020-07-27 add schematic for updated amp
    [left_channel.sch, right_channel.sch]
2020-07-27 install new electrolytic capacitors
    [left_channel.sch, right_channel.sch]
2020-09-01 adding some components to try to stop a high pitch squal sound I sometimes hear from the amp
    [left_channel.sch, nobsound audio amplifier.sch, power supply.sch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]
2020-09-01 change EL84 grid leak resistor to 1M
    In the day time, I sort of feel the amp is too quiet. That adding the 5.6k resistor inline has reduced the signal. This small resistance divide is like 98% the input. But that is still the 2% loss of signal. I think the gain stage of these preamp tubes is not very strong. And I read the EL84 does have a wider response to small changes in input impedance.
    [left_channel.sch, right_channel.sch]
2020-09-02 install vfd spectrograph
    upgrade preamp tubes to use shielded sockets.
    [left_channel.sch, power supply.sch, right_channel.sch]
2020-09-06 remove grid stopped resistors.
    [left_channel.sch, right_channel.sch]
2020-10-07 update schematic
    Replaced all the counterfeit capacitor between preamp and power stage. Really opened up the sound.
    Add some pictures
    [left_channel.sch, nobsound audio amplifier.sch, nobsound.FCStd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]
2020-10-08 It didn't sound right to me
    I don't understand how changing the cathode bypass a bit made the amp a lot more brighter. Theory is the power supply was over loaded before and it was not able to drive the high frequency things out?
    Changed more capacitors. Added plate bypass cap to preamp.
    Sounds much better now.
    [left_channel.sch, nobsound audio amplifier.sch, power supply.sch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]
2020-10-14 remove anode bypass capacitors from preamp
    [left_channel.sch, nobsound.FCStd, right_channel.sch]
2021-04-25 v2.5 modifications
    fix the audio bleedthrough, add soft suspend switch
    [left_channel.sch, nobsound audio amplifier.sch, power supply.sch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]
2021-06-29 updating schematic
    [left_channel.sch, power supply.sch, right_channel.sch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]
